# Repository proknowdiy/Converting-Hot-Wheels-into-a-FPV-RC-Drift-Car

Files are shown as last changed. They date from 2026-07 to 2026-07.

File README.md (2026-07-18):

# 🚗 Converting a $3 Hot Wheels into a Custom 1:64 Scale FPV RC Drift Car

<p align="center">
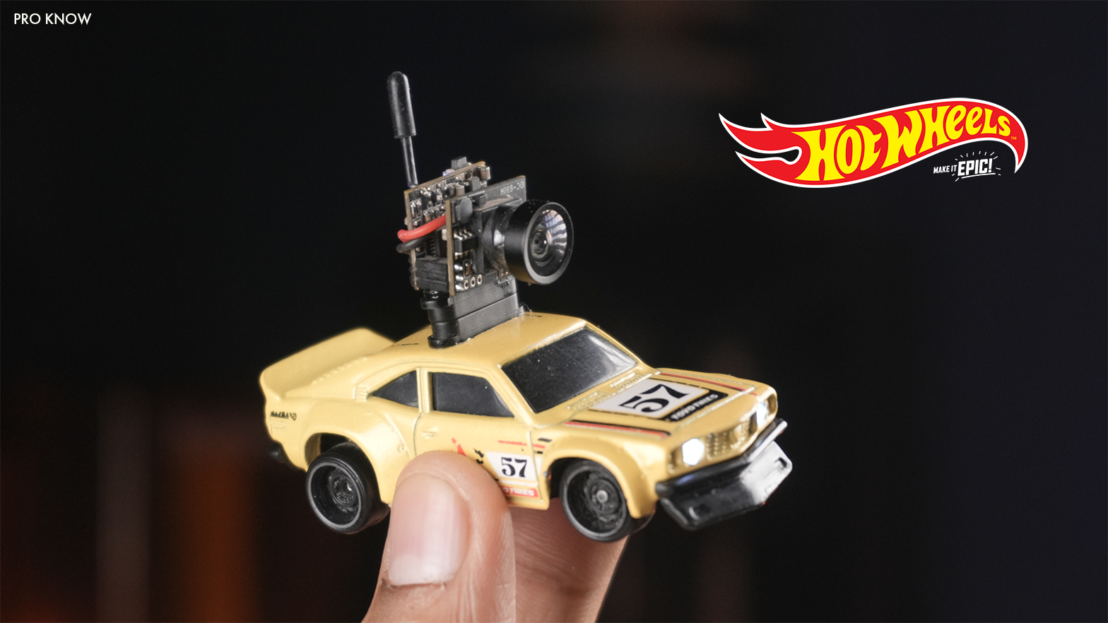
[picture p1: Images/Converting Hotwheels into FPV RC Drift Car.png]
  
</p>

> A fully functional **1:64 Scale FPV RC Drift Car** built from a **Hot Wheels Mazda RX-3**, featuring **ESP-NOW wireless control**, **proportional steering**, **custom PCB**, and a **live FPV camera**.

🎥 **Watch the Full Build Video:**  
https://youtu.be/cxZGm-tz_ug

---

## 📖 About the Project

**नमस्कार मित्रों (Namaskar Mitro),**

In this project, we convert a regular **Hot Wheels Mazda RX-3** into a fully functional **FPV RC Drift Car**.

Despite weighing only **45 grams**, the car features:

- 📡 ESP-NOW Wireless Control
- 🎮 Proportional Steering
- ⚡ Proportional Motor Control
- 💡 Working Headlights
- 📷 Live FPV Camera
- 🔋 Rechargeable Li-Po Battery
- 🔌 Magnetic Charging Connector
- 🖥️ Custom 10mm × 10mm PCB

This repository contains everything required to build your own miniature FPV RC car.

---

# ✨ Features

- ESP8266 (ESP-01F) Based Receiver
- ESP32 ESP-NOW Remote Controller
- Custom 10mm × 10mm PCB
- DRV8212 Motor Driver
- 1.5g Linear Steering Servo
- Coreless Brushed Motor
- FPV Camera System
- Magnetic Charging Port
- Working Headlights
- Compact 45g Design

---

# 🖥 Custom PCB

To fit everything inside such a tiny **1:64 scale** chassis, I designed a custom **10 mm × 10 mm PCB**.

The PCB includes:

- ESP-01F Interface
- DRV8212 Motor Driver
- 3.3V LDO Regulator
- Servo Connector
- Headlight Output
- Backlight Output
- Battery Connector

This makes the electronics extremely compact and easy to assemble.

<p align="center">
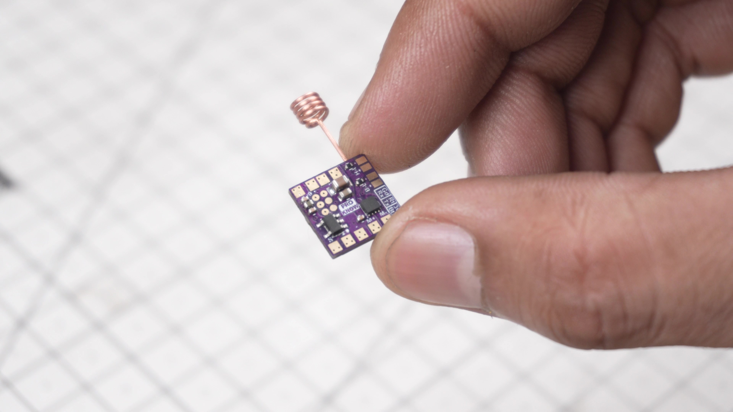
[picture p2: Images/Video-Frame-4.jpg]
  
</p>

---

# 🛠 PCB Manufacturing

The PCB used in this project was manufactured by **JLCPCB**.

If you'd like to build one yourself:

👉 PCB Fab & Assembly from **$2**

https://jlcpcb.com/?from=ProKnow1

🎁 Premium 6-Layer PCB Coupon

https://jlcpcb.com/6-layer-pcb?from=getcoupon

---

# ⚙ Components Used

## 🌍 International

| Component | Link |
|---|---|
| 1.5g Linear Servo | https://s.click.aliexpress.com/e/_c3gl9WDN |
| FPV Camera | https://bit.ly/3SYVMgr |
| FPV Receiver | https://s.click.aliexpress.com/e/_c4mgQJ6b |
| Magnetic Connector | https://s.click.aliexpress.com/e/_c4bnzvun |
| MG90S Servo | https://s.click.aliexpress.com/e/_c3mX4TOF |
| 50mAh LiPo Battery | https://bit.ly/4wQY3sB |
| 2.5mm LED | https://s.click.aliexpress.com/e/_c3zbaSDH |
| 1206 SMD LED | https://bit.ly/3RqyCyO |

Additional Parts

- 2 × M2.5 × 8 mm Standoffs
- Paper Clips / Safety Pins
- 2 × Tongue Cleaners
- Micro Screws Kit

---

## 🇮🇳 India

| Component | Link |
|---|---|
| 1.5g Linear Servo | https://link.amazon/B0aiFIeeu |
| Hot Wheels Mazda RX-3 | https://link.amazon/B07unQC3F |
| FPV Camera | https://link.amazon/B0eynIKSm |
| FPV OTG Receiver | https://bit.ly/4wQLkpO |
| Magnetic Connector | https://bit.ly/4f9rjoz |
| MG90S Servo | https://bit.ly/4wK22Hd |
| 50mAh LiPo Battery | https://bit.ly/4bJqBMj |
| 2.5mm LED | https://bit.ly/4fHVR0I |
| 1206 SMD LED | https://bit.ly/4pAsn8w |

Additional Parts

- 2 × M2.5 × 8 mm Standoffs
- Paper Clips / Safety Pins
- 2 × Tongue Cleaners
- Micro Screws Kit

---

# 📸 Gallery

<p align="center">
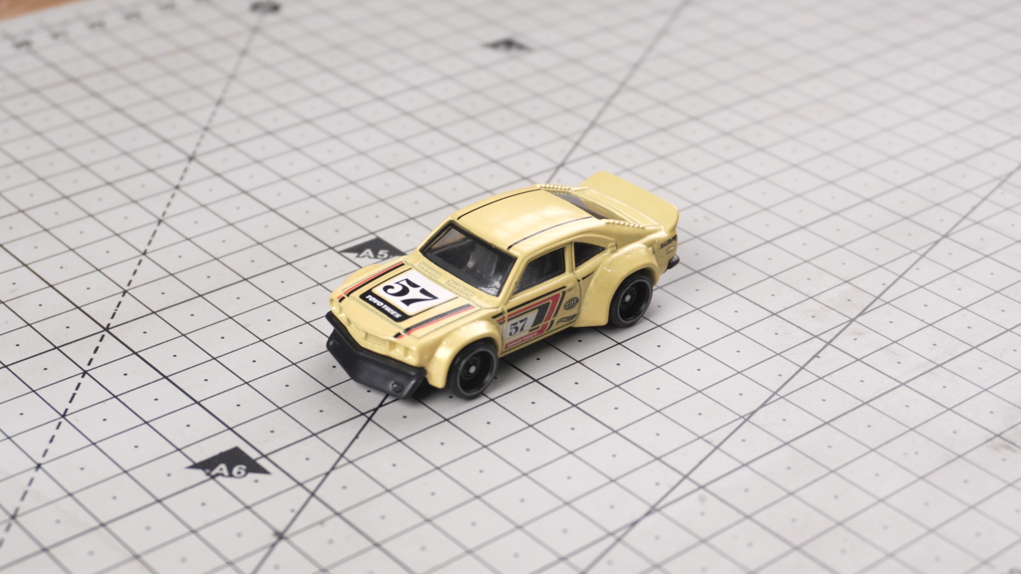
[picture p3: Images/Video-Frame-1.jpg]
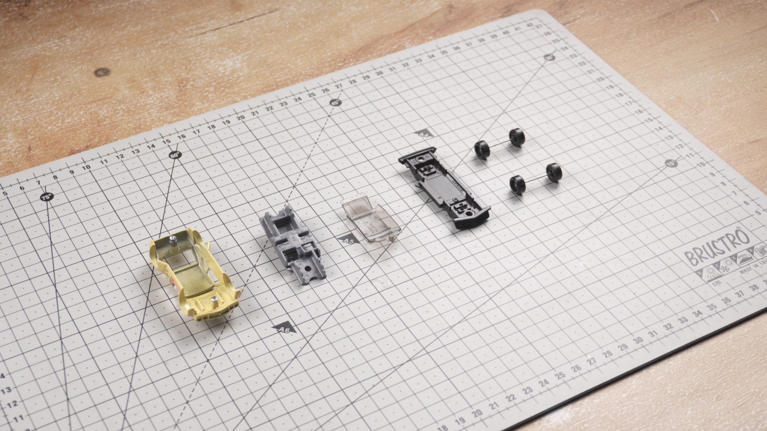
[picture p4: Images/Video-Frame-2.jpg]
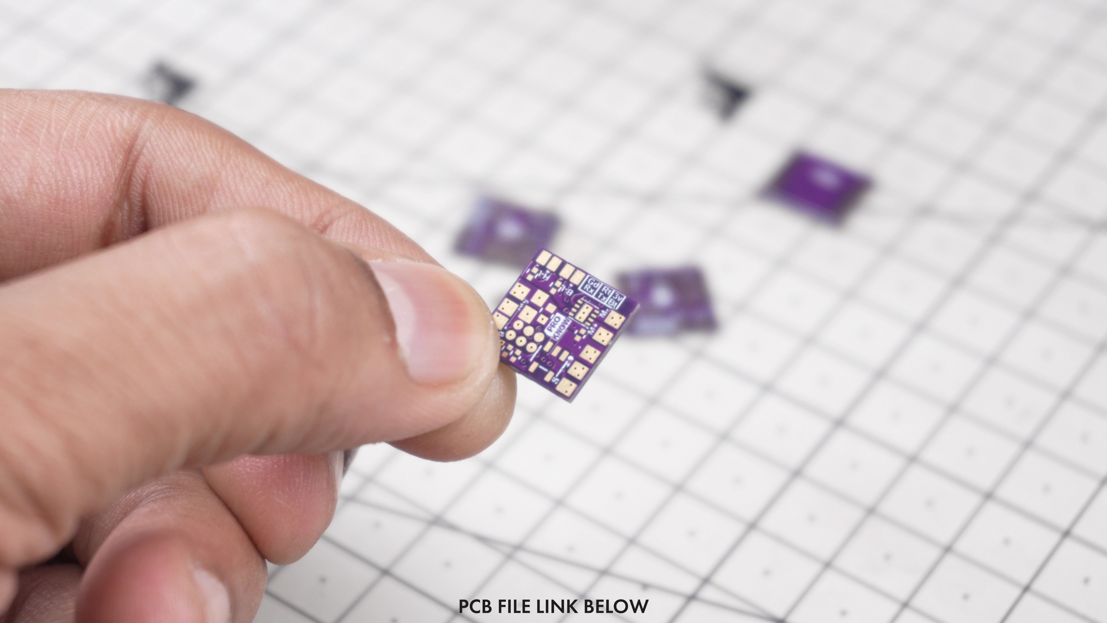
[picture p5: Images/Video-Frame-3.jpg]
    
</p>
<p align="center">
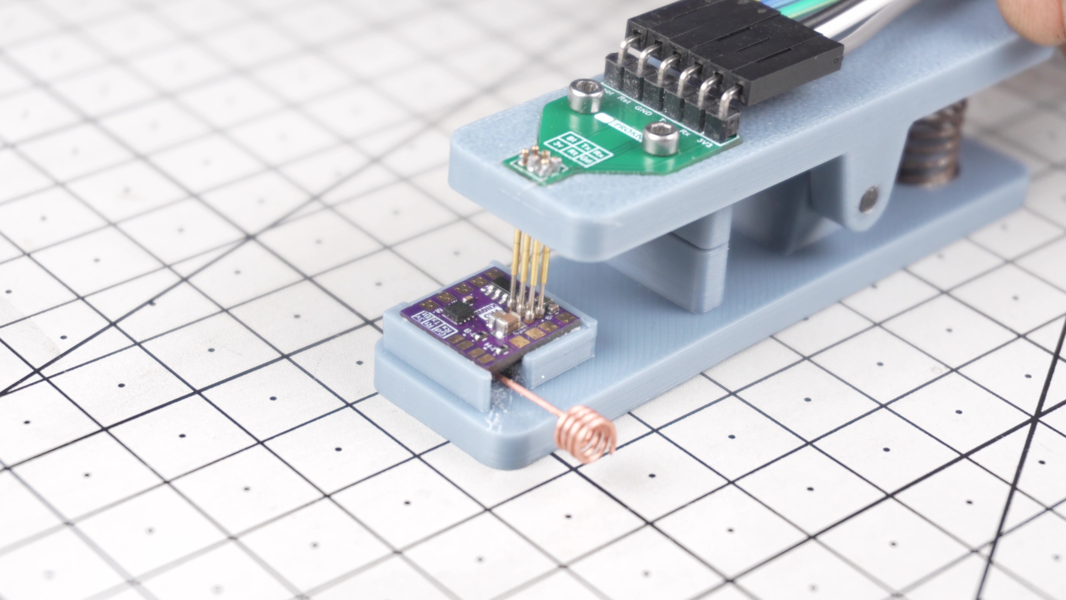
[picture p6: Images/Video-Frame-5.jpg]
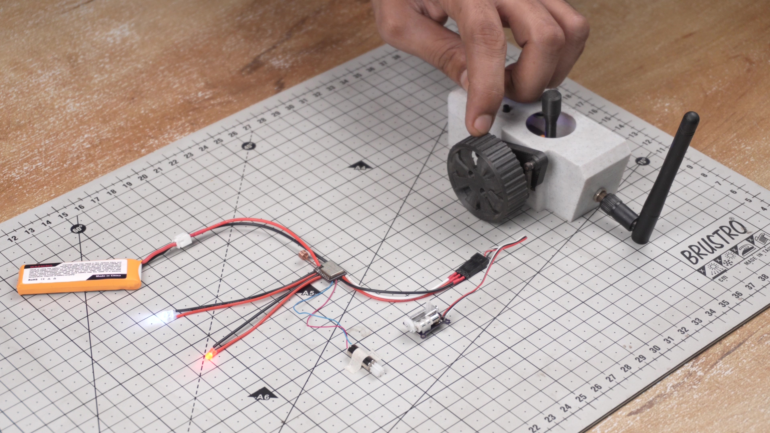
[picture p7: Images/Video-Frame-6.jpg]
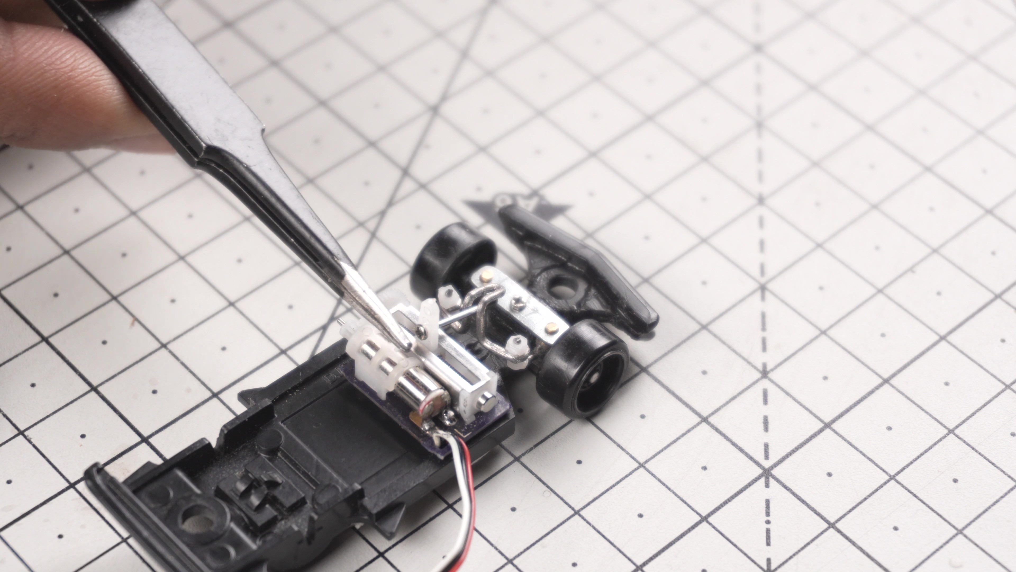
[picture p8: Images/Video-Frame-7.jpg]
    
</p>
<p align="center">
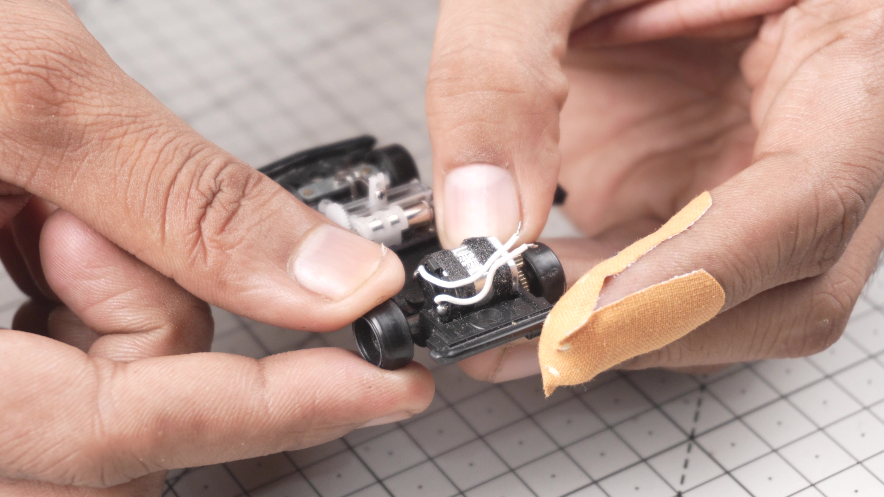
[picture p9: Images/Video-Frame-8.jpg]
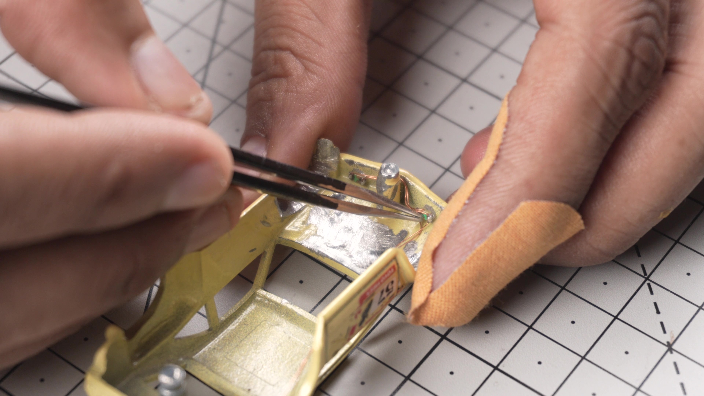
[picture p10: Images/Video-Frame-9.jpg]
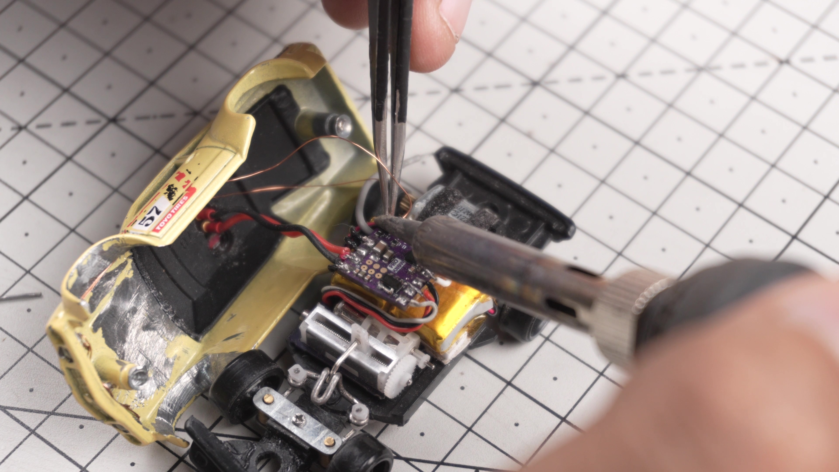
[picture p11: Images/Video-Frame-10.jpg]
    
</p>

---

# 🚀 Getting Started

1. Download the repository.
2. Manufacture the PCB.
3. Print the 3D parts.
4. Assemble the steering mechanism.
5. Solder the electronics.
6. Upload the Receiver firmware.
7. Upload the Transmitter firmware.
8. Bind using ESP-NOW.
9. Enjoy driving!

---

# ❤️ Support the Project

If you enjoyed this project:

⭐ Star this repository

👍 Like the YouTube video

📢 Share it with your friends

🔔 Subscribe to **Pro Know**

---

# 📜 License

This project is shared for **personal and educational use**.

Please do not redistribute or sell the design files without permission.

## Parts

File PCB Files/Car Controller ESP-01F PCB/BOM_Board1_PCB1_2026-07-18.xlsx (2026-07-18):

No. | Quantity | Designator | Footprint | Value | Manufacturer Part | Manufacturer | Supplier Part | Supplier | Comment
1 | 3 | C1,C2,C3 | C0402 | 100nF | CL05B104KB54PNC | SAMSUNG(三星) | C307331 | LCSC | 100nF
2 | 1 | C4 | C0603 | 10uF | GRM188R61E106KA73D | muRata(村田) | C344022 | LCSC | 10uF
3 | 1 | C5 | C0402 | 10uF | CL05A106MP5NUNC | SAMSUNG(三星) | C315248 | LCSC | 10uF
4 | 1 | C6 | C0805 | 22uF | CL21A226MAYNNNE | SAMSUNG(三星) | C602037 | LCSC | 22uF
5 | 6 | H1,H2,H3,H4,H5,H6 | HDR-TH_1P-V-M_XKB_X4611WV-01I-C28D40 |  |  |  |  |  | HDR-M_2.54_1x1P
6 | 1 | H7 | HDR-TH_3P-P2.00-V-M |  | PZ200V-11-03P | XFCN(兴飞) | C541857 | LCSC | PZ200V-11-03P
7 | 2 | H8,H9 | HDR-TH_2P-P1.27-V-M-2 |  | ZX-PZ1.27-1-2PZZ | Megastar(兆星) | C41370734 | LCSC | ZX-PZ1.27-1-2PZZ
8 | 1 | H13 | HDR-TH_6P-P1.27-V-M-R2-C3-S1.27-1 |  | DW127R-22-06-23 | DEALON(德艺隆) | C2935951 | LCSC | DW127R-22-06-23
9 | 1 | L1 | WIFIM-SMD_ESP-01F-2M | 2.4GHz | ESP-01F-2M | Ai-Thinker(安信可) | C2764054 | LCSC | 2.4GHz
10 | 2 | R1,R2 | R0402 | 330Ω | FRC0402F3300TS | FOJAN(富捷) | C2930002 | LCSC | 330Ω
11 | 1 | U1 | TSOT-23-5_L2.9-W1.6-P0.95-LS2.8-BL |  | RT9080-33GJ5 | RICHTEK(立锜) | C841192 | LCSC | RT9080-33GJ5
12 | 1 | U2 | WSON-8_L2.0-W2.0-P0.50-BL-EP_DSG |  | DRV8210DSGR | TI(德州仪器) | C3681199 | LCSC | DRV8210DSGR

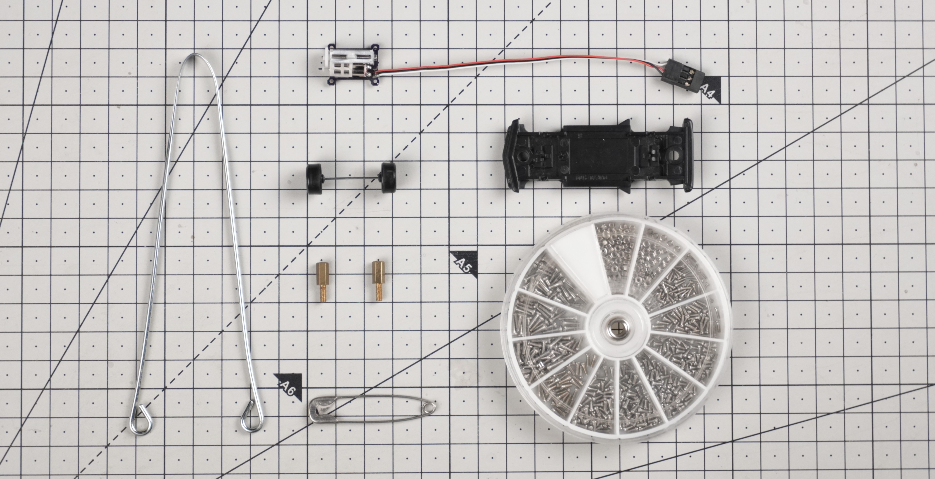
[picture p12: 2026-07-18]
Images/Components-3.JPG

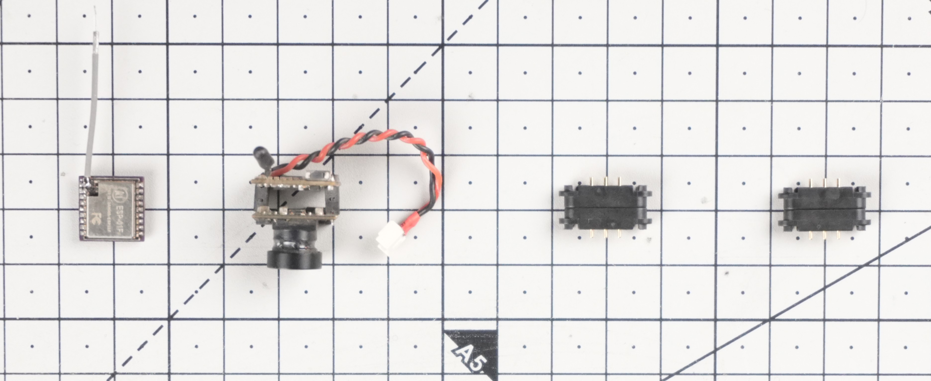
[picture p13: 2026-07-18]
Images/Components-1.JPG

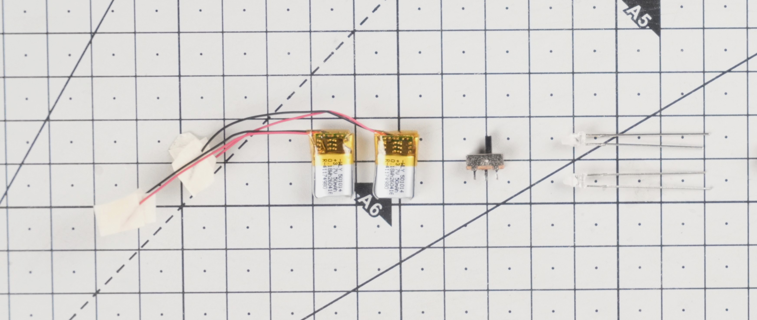
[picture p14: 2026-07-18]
Images/Components-2.JPG

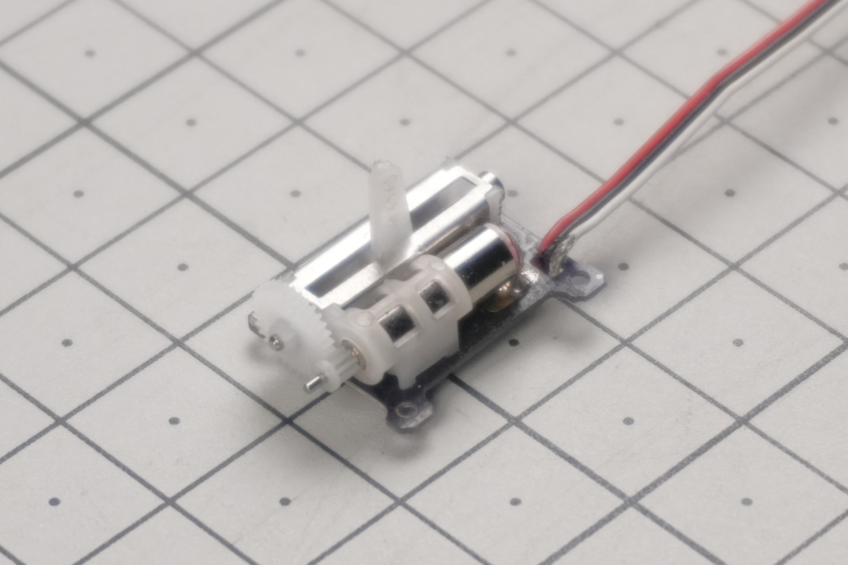
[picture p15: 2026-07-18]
Images/Components-4.JPG

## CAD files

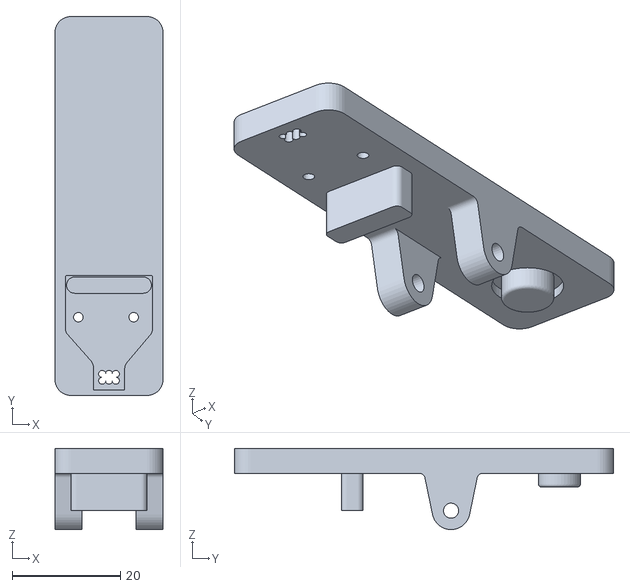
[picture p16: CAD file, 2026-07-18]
CAD Files/Programming Zig Upper Part.stl
20.0 x 70.0 x 15.0

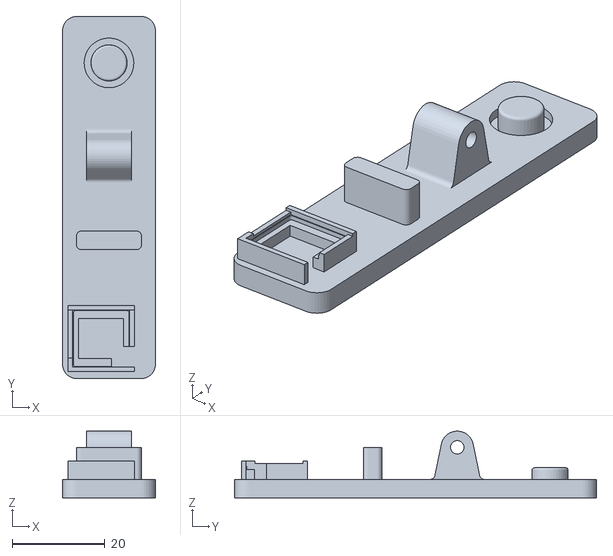
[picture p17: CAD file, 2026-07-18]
CAD Files/Programming Zig Lower Part.stl
20.0 x 78.0 x 14.4

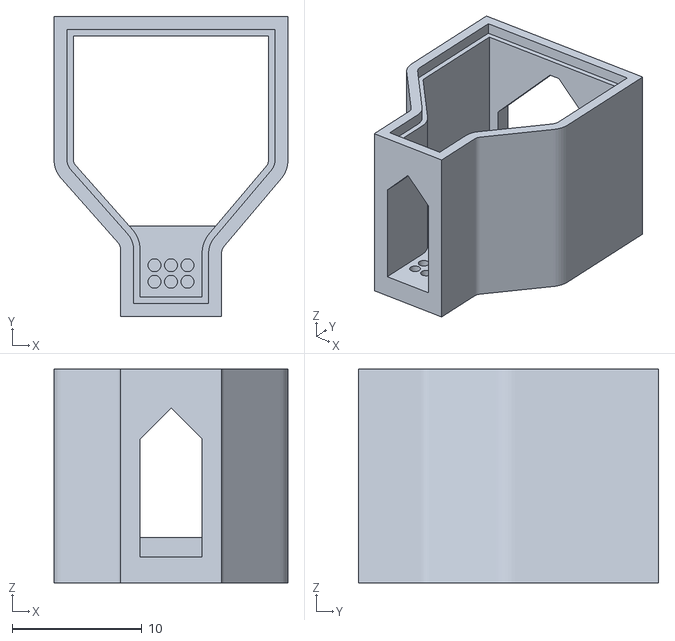
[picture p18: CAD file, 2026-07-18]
CAD Files/Zig to Solder Pogo Pins-v2.stl
18.0 x 23.1 x 16.5

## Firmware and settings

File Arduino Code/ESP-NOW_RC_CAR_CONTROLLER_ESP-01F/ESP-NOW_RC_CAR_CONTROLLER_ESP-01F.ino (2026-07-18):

#include <ESP8266WiFi.h>
#include <espnow.h>
#include <Servo.h>

#define SIGNAL_TIMEOUT 1000  

// Pins
#define SERVO_PIN 12
#define IN1 13
#define IN2 14
#define head_light_pin 4
#define back_light_pin 5

unsigned long lastRecvTime = 0;

typedef struct PacketData
{
  byte throttle;    
  byte steering;    
  bool head_light;
  bool back_light;
  
} PacketData;

PacketData receiverData;

Servo steeringServo;

// Default values
void setInputDefaultValues()
{
  receiverData.throttle = 127;
  receiverData.steering = 132; //127
  receiverData.head_light = 1;
  receiverData.back_light = 1;
}

// 🚗 MOTOR + SERVO + LIGHT CONTROL

void mapAndWriteValues()
{
  // 🎯 Steering Servo
  steeringServo.write(map(receiverData.steering, 0, 254, 40, 180)); //0, 254, 0, 180

  // 🚗 PWM MOTOR CONTROL
  int throttle = receiverData.throttle;

  int deadzone = 5;   // small neutral zone
  int center = 127;

  if (throttle > center + deadzone) {
    int speed = map(throttle, center + deadzone, 254, 0, 1023);
    analogWrite(IN1, speed);
    digitalWrite(IN2, LOW);
  }
  else if (throttle < center - deadzone) {
    int speed = map(throttle, 0, center - deadzone, 1023, 0);
    analogWrite(IN2, speed);
    digitalWrite(IN1, LOW);
  }
  else {
    // Neutral → coast
    digitalWrite(IN1, HIGH);   //LOW/LOW → smooth coast    //HIGH/HIGH → aggressive brake
    digitalWrite(IN2, HIGH);
  }

  // 💡 Lights
  digitalWrite(head_light_pin, receiverData.head_light);
  digitalWrite(back_light_pin, receiverData.back_light);
}

// 📡 Receive callback
void OnDataRecv(uint8_t * mac, uint8_t *incomingData, uint8_t len) 
{
  if (len == 0) return;

  memcpy(&receiverData, incomingData, sizeof(receiverData));

  Serial.printf("T:%d S:%d HL:%d BL:%d\n",
    receiverData.throttle,
    receiverData.steering,
    receiverData.head_light,
    receiverData.back_light);

  mapAndWriteValues();  
  lastRecvTime = millis(); 
}

// Setup pins
void setUpPinModes()
{
  steeringServo.attach(SERVO_PIN, 1000, 2000);

  pinMode(IN1, OUTPUT);
  pinMode(IN2, OUTPUT);
  pinMode(head_light_pin, OUTPUT);
  pinMode(back_light_pin, OUTPUT);

  analogWriteFreq(20000);   // 20kHz (silent, smooth)
  analogWriteRange(1023);   // max resolution

  setInputDefaultValues();
  mapAndWriteValues();
}

void setup() 
{
  Serial.begin(115200);
  delay(1000);
  Serial.println("Receiver Booting...");

  setUpPinModes();

  WiFi.mode(WIFI_STA);

  if (esp_now_init() != 0) 
  {
    Serial.println("ESP-NOW Init Failed");
    return;
  }

  esp_now_set_self_role(ESP_NOW_ROLE_SLAVE);
  esp_now_register_recv_cb(OnDataRecv);

  Serial.println("ESP-NOW Ready");
}

void loop()
{
  // 🔒 FAILSAFE
  if (millis() - lastRecvTime > SIGNAL_TIMEOUT) 
  {
    setInputDefaultValues();
    mapAndWriteValues();  
  }
}

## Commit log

2026-07-18 Programming Zig CAD FIles
    [Programming Zig Lower Part.stl, Programming Zig Upper Part.stl, Zig to Solder Pogo Pins-v2.stl]
2026-07-18 Uploaded PCB Files
    [BOM_Board1_PCB1_2026-07-18.xlsx, PickAndPlace_PCB1_2026_07_18.xlsx]
